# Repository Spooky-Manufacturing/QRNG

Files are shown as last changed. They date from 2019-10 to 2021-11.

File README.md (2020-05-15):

# QRNG
Quantum Random Number Generator

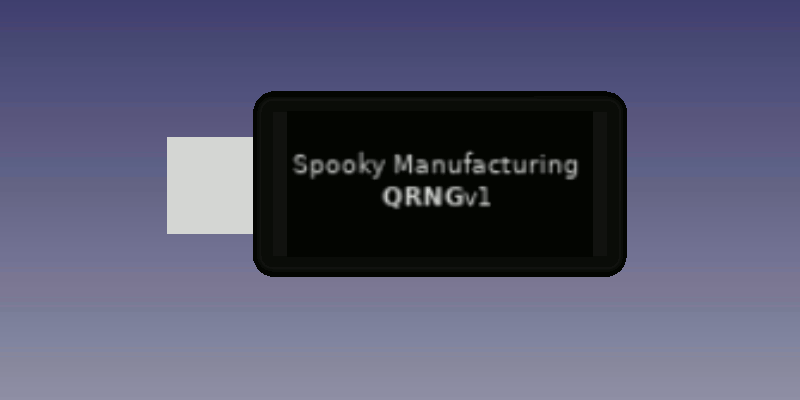
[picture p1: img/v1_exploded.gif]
exploded v1


# Motivation
The QRNGv1 (Now QRNG_BASIC) was originally a proof of concept for quantum technology applications, specifically in this case for the generation of entropy which has a broad range of uses from generating graphics to encryption keys.

# How It Works
The device uses a polarizing beam splitter to split a laser pulse into two beams with a 50/50 probability of a photon in the beam traveling either path. The photons actually travel as a wave, meaning they both pass through and are reflected by the beam splitter. This creates what's known as the superposition of light where the light remains in both paths able to interfere with itself until it is measured and collapses out of superposition.

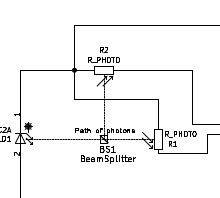
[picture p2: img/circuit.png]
qrng schematic


The equivalent quantum logic gate would be the Hadamard gate, in QASM code:

```qasm
creg c0[1];
h q[1];
measure q[1] -> c0;
```

# Hardware Requirements
- Arduino Uno (or similar)
- Breadboard
- 2x Photoresistors
- 1x 50/50 Polarizing beam splitter
- 1x Laser Diode

# Software Requirements
- Arduino IDE (for programming the Arduino)

# Firmare
Firmware can be found in the respective design folders labelled according to version. The schematics as well are labelled with the version of firmware which supports them.

# How To Use
Currently the QRNG arduino operates via the Arduino Serial Monitor, you can issue single letter commands to it. We plan to add support for the device with our [Qubit Controller](https://github.com/Spooky-Manufacturing/Qubit-Controller) in the near future.

## Available Commands
- v : Version, returns the current firmware verison
- t : Test command, should return 'Success!' on the monitor
- e : Enables extraneous information
- r : Returns a random bit generated by the RNG
- h : Produces a hadamard operation on the qubit, returning the measured angle of the qubit

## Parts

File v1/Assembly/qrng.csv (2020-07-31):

Designator | Quantity | Value | Cmp name | Footprint | LCSC Part #
C1, | 1 | 4.7uF | C_Small | Capacitor_SMD:C_0402_1005Metric | C23733
C9, C8, | 2 | 10uF | C_Small | Capacitor_SMD:C_0402_1005Metric | C15525
C10, C2, C3, C4, C5, C6, C7, | 7 | 100nF | C_Small | Capacitor_SMD:C_0402_1005Metric | C1525
C11, | 1 | 10nF | C_Small | Capacitor_SMD:C_0402_1005Metric | C14195
C12, C13, | 2 | 30pF | C_Small | Capacitor_SMD:C_0603_1608Metric | C22397
D1, | 1 | B5819W | ZENER | Diode_SMD:D_SOD-123 | C8598
D2, | 1 | LED | LED | LED_SMD:LED_0805_2012Metric | C24499
FB1, FB2, | 2 | 100ohm @ 100mHz | Ferrite_Bead_Small | Inductor_SMD:L_0805_2012Metric | C1015
R4, | 1 | 270 | R_Small_US | Resistor_SMD:R_0603_1608Metric | C22965
R5, | 1 | 100 | R_Small_US | Resistor_SMD:R_0603_1608Metric | C25803
U1, | 1 | AMS1117 | AMS1117 | Package_TO_SOT_SMD:SOT-223-3_TabPin2 | C6186
U2, | 1 | STM32F103C8Tx | STM32F103C8Tx | Package_QFP:LQFP-48_7x7mm_P0.5mm | C8734
U3, | 1 | W25N01GV | W25Q64FWZP | Package_SON:WSON-8-1EP_6x5mm_P1.27mm_EP3.4x4mm | C88868
Y1, | 1 | 8 MHz | Crystal | Crystal:Crystal_SMD_5032-2Pin_5.0x3.2mm_HandSoldering | C115962

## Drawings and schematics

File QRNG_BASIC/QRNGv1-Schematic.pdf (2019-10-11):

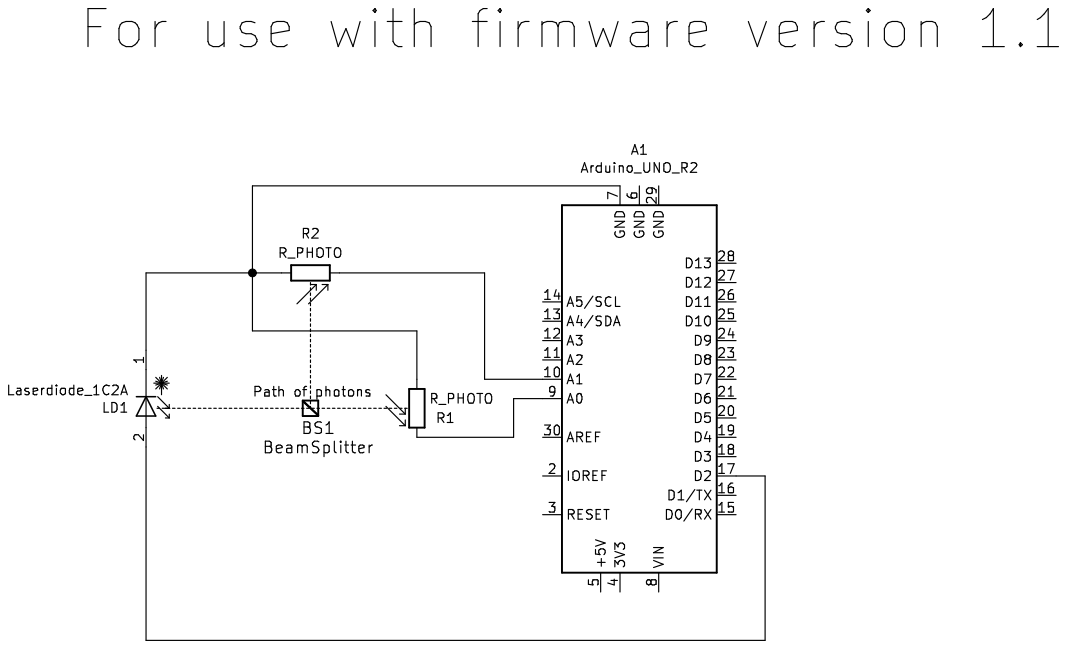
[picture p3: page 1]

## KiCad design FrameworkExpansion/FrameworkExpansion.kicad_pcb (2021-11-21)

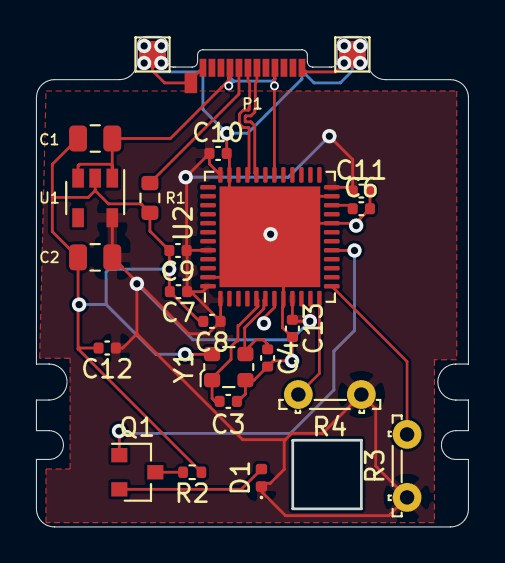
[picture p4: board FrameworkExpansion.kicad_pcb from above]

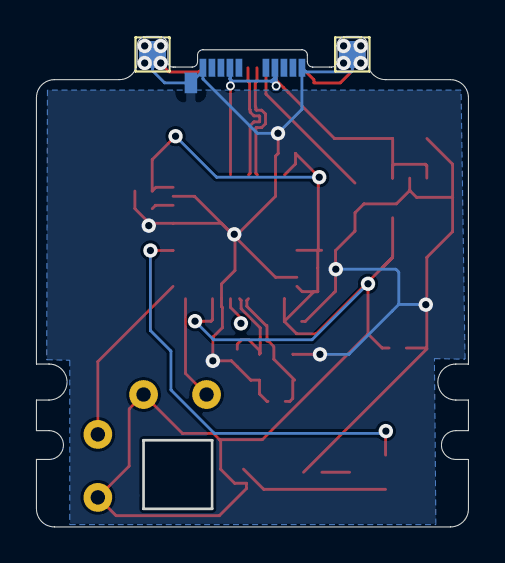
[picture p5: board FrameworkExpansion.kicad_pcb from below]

Board: 2 copper layers, 24.0 x 27.3 mm, 26 parts (2 on the bottom side), 14 nets.

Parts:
C1, C2: 10uF; C_0805_2012Metric
C3, C4: C_Small; C_0402_1005Metric
C6: 4.7uF; C_0402_1005Metric
C7, C8, C9, C10, C11, C12, C13: 100nF; C_0402_1005Metric
D1: LED; LED_0402_1005Metric
P1: USB_C_Plug_USB2.0; USB_C_Plug_Molex_105444
Q1: Q_NPN_BCE; SOT-23
R1: 5.1k; R_0603_1608Metric
R2: 10k; R_0402_1005Metric
R3, R4: R_PHOTO; R_LDR_5.2x5.2mm_P3.5mm_Horizontal
TP1, TP2, TP3, TP4: TestPoint; TestPoint_Pad_1.5x1.5mm
U1: AP2112K-3.3; SOT-23-5
U2: STM32F411CEUx; QFN-48-1EP_7x7mm_P0.5mm_EP5.6x5.6mm
Y1: Crystal_GND24; Oscillator_SMD_ECS_2520MV-xxx-xx-4Pin_2.5x2.0mm

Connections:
+3V3: C2.1, C7.1, C8.1, C9.1, C10.1, C11.1, C12.1, C13.1, D1.1, R3.1, R4.1, U1.5, U2.1, U2.9, U2.24, U2.36, U2.44, U2.48
/HORIZONTAL: R4.2, U2.12
/TRIGGER: Q1.1, U2.17
/USB_DN: P1.A7, U2.32
/USB_DP: P1.A6, U2.33
/VERTICAL: R3.2, U2.13
/XTAL_N: C4.1, U2.6, Y1.3
/XTAL_P: C3.1, U2.5, Y1.1
GND: C1.2, C2.2, C3.2, C4.2, C6.2, C7.2, C8.2, C9.2, C10.2, C11.2, C12.2, C13.2, P1.A1, P1.A12, P1.B1, P1.B12, P1.S1, R1.2, R2.1, TP1.1, TP2.1, TP3.1, TP4.1, U1.2, U2.8, U2.20, U2.23, U2.35, U2.47, U2.49, Y1.2, Y1.4
unnamed: C6.1, U2.22
unnamed: D1.2, Q1.2
unnamed: P1.A5, R1.1
unnamed: Q1.3, R2.2
VBUS: C1.1, P1.A4, P1.A9, P1.B4, P1.B9, U1.1, U1.3, U2.30

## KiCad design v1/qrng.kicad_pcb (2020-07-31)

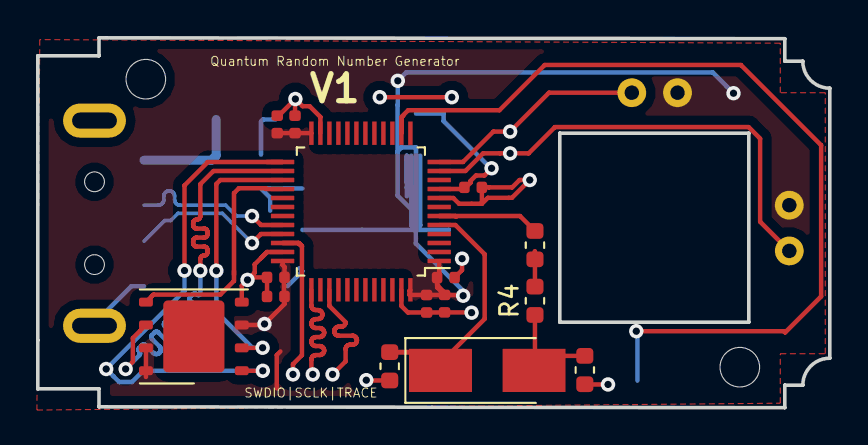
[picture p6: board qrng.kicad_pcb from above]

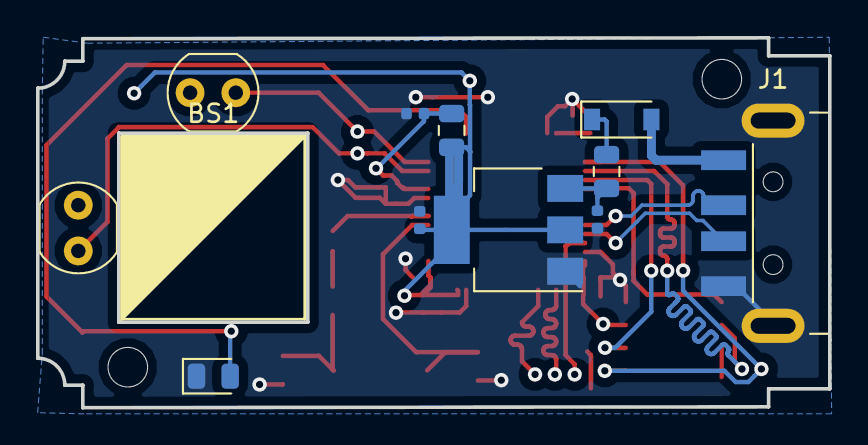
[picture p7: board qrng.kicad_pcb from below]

Board: 2 copper layers, 44.0 x 20.5 mm, 29 parts (12 on the bottom side), 19 nets.

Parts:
BS1: Macro-Beam-Splitter
C1: 4.7uF; C_0402_1005Metric
C2, C3, C4, C5, C6, C7, C10: 100nF; C_0402_1005Metric
C8, C9: 10uF; C_0402_1005Metric
C11: 10nF; C_0402_1005Metric
C12, C13: 30pF; C_0603_1608Metric
D1: B5819W; D_SOD-123
D2: LED; LED_0805_2012Metric
FB1, FB2: 100ohm @ 100mHz; L_0805_2012Metric
H1, H2: MountingHole; MountingHole_2.2mm_M2
J1: USB_A; USB_A_CNCTech_1001-011-01101_Horizontal
R2, R3: R_PHOTO; R_LDR_4.9x4.2mm_P2.54mm_Vertical
R4: 270; R_0603_1608Metric
R5: 100; R_0603_1608Metric
U1: AMS1117; SOT-223-3_TabPin2
U2: STM32F103C8Tx; LQFP-48_7x7mm_P0.5mm
U3: W25N01GV; WSON-8-1EP_6x5mm_P1.27mm_EP3.4x4mm
Y1: 8 MHz; Crystal_SMD_5032-2Pin_5.0x3.2mm_HandSoldering

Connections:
+3.3VA: C10.1, C11.1, FB2.1, U2.9
+3V3: C1.1, C2.1, C3.1, C4.1, C5.1, C6.1, C7.1, C9.1, FB2.2, R2.2, R3.1, U1.2, U2.1, U2.24, U2.36, U2.48, U3.3, U3.7, U3.8
+5V: D1.2, J1.1
ADC1: R3.2, U2.11
ADC2: R2.1, U2.12
GND: C1.2, C2.2, C3.2, C4.2, C5.2, C6.2, C7.2, C8.2, C9.2, C10.2, C11.2, C12.1, C13.1, D2.1, J1.4, J1.5, U1.1, U2.8, U2.23, U2.35, U2.47, U3.4
MEM_MISO: U2.27, U3.2
MEM_MOSI: U2.28, U3.5
MEM_NSS: U2.25, U3.1
MEM_SCK: U2.26, U3.6
unnamed: C8.1, FB1.1, U1.3
unnamed: C13.2, R4.1, Y1.2
unnamed: D1.1, FB1.2
unnamed: R4.2, R5.1
OSC_IN: C12.2, U2.5, Y1.1
OSC_OUT: R5.2, U2.6
USB_D+: J1.3, U2.33
USB_D-: J1.2, U2.32
trigger: D2.2, U2.14

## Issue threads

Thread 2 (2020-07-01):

Question about detection

Quantizr, 2020-07-01:
Hi, I'm a high schooler who is interested in quantum physics and quantum computing. I have a very limited understanding of quantum computing at the moment, and I'm having trouble understanding how your QRNG design produces random numbers.  This is how I understand your device:

As you stated in your article, there are trillions of photons in each light pulse. Each individual photon has a 50% chance to collapse into a vertical or horizontal state. As an example, assuming exactly 1 trillion photons pass through, approximately 500 billion photons would be vertically polarized, and approximately 500 billion would be horizontally polarized. Photoresistors of the type used in this device are not able to detect light to the photon level, so, in theory, both resistors should provide a resistance with an unmeasurable difference. Any measurable difference in voltage would be caused by background light, imperfectly angled sensors, dark counts, or variance within the measuring tool. As far as I understand, what actually is happening is RNG created by radiation/noise from the background or from the hardware, which, while it should be truly random, is not quantum randomness. Another implication is that using an expensive polarized beamsplitter is completely unnecessary in that case, as a cheaper non polarized 50/50 beamsplitter would work just fine.

I just re-read the original article and found you were originally using a 650nm red laser diode. If I recall correctly, lasers emit polarized light, meaning that the quantum state of the photons is already collapsed at the moment of leaving the laser, making the entire RNG pointless. I'm not sure if the same is true with LEDs though. Anyway, the point is, as far as I understand it, single photon generation and detection is required for this form of quantum number generation. However, I am still just a high school student with very little knowledge about quantum physics, so I'm very likely wrong about this whole thing. It'd be great if you could clarify what I'm missing here.

Final note: I am almost completely confident of this: one cannot perform a Hadamard transform on more than a single photon and it would not in any way return the superposition measurement (I assume that is what you mean by qubit angle? though I'm not sure what you mean by angle... is it the angle of the linear combination of basis states vectors?). A measurement after a Hadamard transform would just collapse it back to a single basis state and not give a measurement as far as I'm aware.

dakk, 2020-07-22:
Despite the @Quantizr assumptions and implications seems correct, I've found this experiment/project https://directory.eoportal.org/web/eoportal/satellite-missions/s/spooqy-1 which as far as I understand creates (in space) an experiment like QRNG. It uses many non linear optical filters to create a pair of entangled photons starting from a blue laser beam (which, as @Quantizr noted, produces a beam of same-phase photons).

Anyway, I'm not a physicist or an engineer and my quantum knowledge is barely zero, so my comment is valuable only for the link.

NoahGWood, 2021-03-10:
Apologies for the (Long) hiatus.

**"Each individual photon has a 50% chance to collapse into a vertical or horizontal state. As an example, assuming exactly 1 trillion photons pass through, approximately 500 billion photons would be vertically polarized, and approximately 500 billion would be horizontally polarized."**

Yes

**"Photoresistors of the type used in this device are not able to detect light to the photon level, so, in theory, both resistors should provide a resistance with an unmeasurable difference."**

In theory, yes.

**"Any measurable difference in voltage would be caused by background light, imperfectly angled sensors, dark counts, or variance within the measuring tool."**
That is an assumption, and one I had as well.

If background light were the primary cause, we should expect the RNG to work without the addition of light, it does not. Imperfectly angled sensors weights the randomness, pretty heavily, resolving that is part of the tuning process.

Dark counts are not really a significant issue just because of the sheer volume of photons we're working with and because photoresistors are really insensitive.

There is the issue of residual electricity in the circuit - that could definitely cause a problem (and did cause a heavy weighting problem at first), but you'll notice in the firmware we added a delay - this was placed there to ensure that both sensors drained fully.

Unfortunately we're working with a single arduino here and I don't have the necessary equipment to more thoroughly test the device for any measurement issues.

With that being said, generally these kinds of issues don't induce randomness, they reduce it. If, say, the H wire is pushing some residual electricity into the V wire we should expect to see more V counts than H counts and vice versa.

**"As far as I understand, what actually is happening is RNG created by radiation/noise from the background or from the hardware, which, while it should be truly random, is not quantum randomness."**
Background radiation is 100% not the cause, you're welcome to test it out yourself if you like though.

Hardware issues, I mean, maybe? An electrical pulse is actually generated when light hits the photoresistors, in the V1 arduino model you'll notice the photoresistors are tied directly to ground, so the voltage spike measured is the voltage generated by the light itself, this could induce some kind of inductive currents that messes with the ADC I guess? The ground isn't floating either, I had diodes on my first set up to prevent backflow, but it didn't seem to make a difference in the results

**"Another implication is that using an expensive polarized beamsplitter is completely unnecessary in that case, as a cheaper non polarized 50/50 beamsplitter would work just fine."**
Possibly, but I don't think it will be operating on the same principles, that might be fun to try though

**"If I recall correctly, lasers emit polarized light"**
_All_ light is polarized.
Lasers simply emit light that is _mostly_ polarized _in a specific direction_. It can be kind of confusing, polarization is an inherent part of any electromagnetic wave, we're using linearly polarized light which is why I'm using simpler terms like vertical/horizontal, it's all relative to the observer.

**"meaning that the quantum state of the photons is already collapsed at the moment of leaving the laser"**
Nope, even the linear polarization of a laser is only a probabilistic function. Try it out for yourself, take a laser pointer and point it at a wall 20 or 30' away, now start walking towards it. The laser point starts out big and gets smaller, if it were perfectly polarized there would be no beam widening.

**"single photon generation and detection is required for this form of quantum number generation."**
Well, this design is specifically so that we can use a collection of photons to perform the computation and avoid the very pricey components

**"Final note: I am almost completely confident of this: one cannot perform a Hadamard transform on more than a single photon at a time and it would not be able to return the superposition measurement (I assume that is what you mean by qubit angle?"**
We can, we just have to be realistic that the only results we will be able to get are an average of each individual photon. Maybe I should have lead with that, build the device and rotate the laser diode, if you take the tangent of the input voltages H/V you will find the average polarization angle of all the photons in the laser pulse, when properly tuned that angle will be 45*.

The "qubit" I'm referring to in the paper is the simulated qubit which is effectively the average of every photon the hadamard was performed on. The angle is just that, the angle of the polarization of our simulated qubit.

And I should mention that aforementioned angle isn't exact, it's a bit wonky to even describe, basically the calculated angle should always be between 0-90, there is some information loss there and if you think of the polarization angle as a line drawn through a circle with four quadrants, we're able to recover only one quadrant, and we don't even know which one that is, only that it is intersected by a line with that angle. So 45* could actually be 135* or 225*, etc. It's really only useful for tuning the device.
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
Quantizr, 2021-03-10:
**Forget what I said above, its all a big jumble of thoughts, but my main conclusion is this. Use your same setup, same code, same photoresistors, but get rid of the beamsplitter and laser. Place a lightbulb close to the photoresistors and tune for bias. You should see randomness in the exact same way as you had with the beamsplitter and laser.**

Now that I think of it, I know exactly why your original design does not work as you think it does.
A back of the napkin calculation says that a 1mW laser with photons equally divided across two photoresistors says each photoresistor would receive around 160 billion photons every 104 microseconds (Arduino ADC time interval). Optimally, each photoresistor would receive exactly 80 billion photons over the time interval, but we know that isn't always the case. We do know that the amount of photons received follows an approximately normal distribution (photon shot noise follows Poisson distribution, approaches normal at large counts). We can calculate the margin of error (use alpha 0.05 for convenience) = 1.96 * √0.5 * (1 - 0.5) / √160,000,000,000 = 1.73241161e-6 which is an approximately 0.000173% margin of error. Let's assume that at precisely 160 billion photons/104microseconds, the photoresistors output exactly 2.000000 volts.

**Your measuring equipment must be able to measure to an accuracy of 0.00346 mV if you wish to generate randomness from a laser beam, far less than the 4.88mV which an Arduino can calculate to.**

C-Bookie, 2021-11-09:
I'm sure every random function is influenced by quantum events of the past, but I like this toy example

QbitCreator, 2022-01-16:
The system used in this case is called a vacuum fluctuation QRNG and is indeed a well proven concept. The doubt regarding this hardware realisation however, is understandable. I will experiment with this setup and give my feedback how well it works or what improvements could be made aswell...

anonfreak191, 2022-12-30:
I think it would be better to put both photo resistors in a voltage divider configuration. There is way to increase your ADC bit count (not physically but virtually), you split the voltage up into two or more analogue inputs, then in your code you can add them up to form a single number with a resolution of more than 10 bits. Also the 5v output of an arduino is very noisy, so its best to add a smoothing circuit. E.g,  LDR and resistor voltage divider setup, feed the divider 10v, and depending on light it should vary between 0v to 10v, then run it through another divider to split the voltage 50/50, then run those two varying 0v to 5v lines through an analog pin, in your code you can add them together for a total resolution of 0-2046 which is far greater than the ADC 10bits (0-1023).

Hegezcc, 2023-07-07:
It is well worth to note, in firmware level (QRNG_BASIC/firmware/v1.1/v1.1.ino) the measurements are done until a difference between analog reads is seen, and that difference (or rather, its side) is then reported as random bit. I personally do not have any numbers about how many times the loop is actually executed, but this primarily causes the generator not to have a time guarantee, but rather trade time for its ADC precision.

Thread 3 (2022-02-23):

Loss of randomness

derekburgess, 2022-02-23:
I recreated your example from an article and it was working as expected, generating seemingly random 1's and 0's. I wanted to scale it up in size as well as add an OLED to print the results. After which, it continued to "work", but now it seems to have lost its randomness and only prints 1's -- Any thoughts on what might cause this? I have triple checked wiring and have even reverted my build back to the original scope, still it only produces a 1.

NoahGWood, 2022-02-24:
Hi, Derek!

The most common cause of this issue is that the polarization of the photons coming from the laser is not at exactly a 45 degree angle relative to the beam splitter. This causes an unequal distribution in the number of photons being reflected/transmitted through the beam splitter.

When a photon hits a polarized beam splitter it is either reflected or transmitted. The probability of the photon being reflected or transmitted by a polarized beam splitter is directly related to how close the polarization of the photon and beam splitter are to one another.

A horizontally polarized beam splitter only allows photons through which are horizontally polarized and reflects the vertically polarized photons. The randomness comes from the angle in-between 0 and 90, a photon polarized at exactly 50% of the difference between these two angles (45 degrees) will collapse into either the horizontal or vertical mode with equal probability of reflection or transmission. This is the basis of the optical circuit.

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

Now, this is what I suspect to be the problem you've run into, and that is a when a photon does not match the 45 degree angle. A photon who is polarized closer to 90 degrees, say 75 degrees, will more often than not collapse into the vertical mode and be reflected. Likewise a photon whose relative polarization is closer to 0 degrees, let's say 10 degrees, will more often than not collapse into the horizontal mode and be transmitted.

Now, there are several trillion photons being generated and pushed through the entropy generator every pulse. If the laser is putting out photons which weighted towards one polarization over the other, that side of the circuit is more likely to receive more photons which decreases the resistance of the LDR which increases the voltage and ultimately causes the imbalance you are seeing.

I don't recall if it was discussed in the article or not, but you can try rotating the body of the laser diode while it is operating to "tune" the polarization until you wind up with a random distribution. This is what I originally did when I first designed it, alternatively you can place a 45 degree polarizing lens in front of the laser which is a more elegant solution.

The other possible issue is the Arduino itself because you are taking measurements at two separate times there is a possibility that the LDR which is being measured first is going to be higher than the LDR measured next. It's unlikely to be significant enough to measure on the Arduino, but you can try adjusting this in firmware by adding a small number to the voltage of either side to account for that.

Let me know if any of this helps you!

derekburgess, 2022-02-24:
Appreciate the reply, adjusting the angle of the pointer started producing more randomization. I will continue to toy with it tomorrow.

derekburgess, 2022-02-24:
Noah, this was it. I had upgraded the laser diode to a slightly larger version, with the same specifications, but I could not find a positioning that would make it work. I suspect that laser is either incorrectly labeled or creating distancing issues.

I returned to the laser diode similar to the one you use and was able to resolve the issue.

I am fascinated by the amount of variance which is possible with minor adjustments to position. I also found distance from the beamsplitter to impact results, is this expected?

Also while I have you, In the past I have used resistors inline with photo-resistors. Not sure I fully understand why this works without them? Since I get nearly the same voltage reading from both photo-resistors.

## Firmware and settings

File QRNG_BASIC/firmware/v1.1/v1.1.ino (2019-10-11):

/*      QRNGv1 Firmware V1.1
 * Author: Noah G. Wood
 * 
 * Copyright (c) 2019 Spooky Manufacturing, LLC
 * License: GPLv3.0
 * 
 */
int triggerPin = 2;
int hPin = A0;
int vPin = A1;
float H = 0;
float V = 0;
bool xtra = 0;

void setup() {
  // put your setup code here, to run once:
  pinMode(13, OUTPUT);
  pinMode(triggerPin, OUTPUT);
  Serial.begin(9600);

}

float angle() {
  float a = degrees(atan(V/H));
  return a;
}

void HGate() {
  digitalWrite(triggerPin, HIGH);
  digitalWrite(triggerPin, LOW);
  H = analogRead(hPin);
  V = analogRead(vPin);
}

int Rand() {
  HGate();
  if(H > V) {
    return 0;
  } if(H < V) {
    return 1;
  } else {
    Rand();
  }
}
void extra(){
  if(xtra){
    Serial.print("\nH: ");
    Serial.print(H);
    Serial.print("\nV: ");
    Serial.print(V);
    Serial.print('\n');
  }
}
void loop() {
  if(Serial.available()){
    char val = Serial.read();
    if(val == 'e') {
      if(xtra == 0){
        Serial.print(">Printing Extra Information\n");
        xtra=1;
      } else{
        Serial.print(">Not Printing Extra Information\n");
        xtra=0;
      }
    }
    if(val == 'h') {
      HGate();
      Serial.print(angle());
      Serial.print('\n');
      extra();
    }
    if(val == 'r') {
      Serial.print(Rand());
      Serial.print('\n');
      extra();
    }
    if(val == 't') {
      Serial.print("Success!\n");
    }
    if(val == 'v'){
      Serial.print("Version 1.1\n");
    }  }
}

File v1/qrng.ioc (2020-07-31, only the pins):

Mcu.UserName=STM32F103CBTx
PA1.Signal=ADCx_IN1
PA11.Signal=USB_DM
PA12.Signal=USB_DP
PA13.Signal=SYS_JTMS-SWDIO
PA14.Signal=SYS_JTCK-SWCLK
PA2.Signal=ADCx_IN2
PA4.Signal=GPIO_Output
PB12.Signal=SPI2_NSS
PB13.Signal=SPI2_SCK
PB14.Signal=SPI2_MISO
PB15.Signal=SPI2_MOSI
PB3.Signal=SYS_JTDO-TRACESWO
PD0-OSC_IN.Signal=RCC_OSC_IN
PD1-OSC_OUT.Signal=RCC_OSC_OUT

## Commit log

2019-10-11 Created QRNGv1
    [QRNGv1.kicad_pcb, QRNGv1.sch]
2020-05-15 Renamed v1 to "BASIC" Created a new v1 design which integrates USB, microcontroller, and storage Updated readme Add PCB layout, gerber, and assembly files
    [QRNGv1.kicad_pcb, QRNGv1.sch, qrng.kicad_pcb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]
2020-07-31 Separated ADC pins per recommendation from Epilogis
    [qrng-B.Cu.gbr, qrng-B.Mask.gbr, qrng-B.Paste.gbr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]
2021-11-21 new file: FrameworkExpansion/Expansion_Card.pretty/Framework-Logo_1.5mm_SilkScreen.kicad_mod new file: FrameworkExpansion/Expansion_Card.pretty/PinSocket_8FM-78-0010-02-146_1x10_P2.54mm_Horizontal_SM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
    [FrameworkExpansion.kicad_pcb, FrameworkExpansion.sch, rng.sch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]

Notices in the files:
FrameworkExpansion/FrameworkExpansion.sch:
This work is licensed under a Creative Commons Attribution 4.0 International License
